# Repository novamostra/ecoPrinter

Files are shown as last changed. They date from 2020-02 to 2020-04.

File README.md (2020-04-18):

# ecoPrinter
ecoPrinter is an innovative device which can replace hard copies with **no interaction** file transferring, by implementing Android Beam and USB Printer Gadget functionality on a Raspberry PI Zero W.

Forget searching for Bluetooth devices or Wifi networks, enabling visibility, establishing a connection/pairing or setting up Wifi Direct, everything has become automated using (the unfortunately now deprecated) Android Beam. You just place your mobile device on the ecoPrinter while this is searching for a device (Red indication Light) and a few seconds later you can view the file on your mobile device as PDF. No matter if it is an image, document or a web-page, full backward compatibility is guaranteed because ecoPrinter appears as any other Printing device  on your computer.

The main idea for this device is to reduce the amount of paper we use and also help users organize and keep their receipts, invoices, documents with the minimum amount of effort.
<!--more-->
## How it works
1. The provider (owner of the device) connects the ecoPrinter and correlates the appropriate driver.
2. The provider of the ecoPrinter functionality simply selects the document to be printed and selects ecoPrinter as the preferable printer device.
3. The file is then send to the Raspberry Pi and is converted to PDF.
4. The WS2812B indicates to the user that it's time to place the mobile device to the ecoPrinter
5. With no other interaction the file is transferred to the mobile device as a PDF.

## Schematic
ecoPrinter schematic

## Configuration/Setup
1. Clone the repository
2. Set execute permission to setup.sh
```bash
sudo chmod +x setup.sh
```
3. Run as sudo
```bash
sudo ./setup.sh
```
4. On your Windows computer setup the appropriate printer driver running the following command:
```
printui /if /b "ecoPrinter" /f %windir%\inf\ntprint.inf /m "Microsoft PS Class Driver" /r "USB001"
```
5. Your ecoPrinter is Ready!

The complete step by step guide on how to create your own ecoPrinter is available on [instructables](https://www.instructables.com/id/EcoPrinter/).

## 3d files are also available at Thingverse
[Download from Thingverse](https://www.thingiverse.com/thing:4164764)

[Find out more](https://novamostra.com/2020/02/15/ecoprinter/)

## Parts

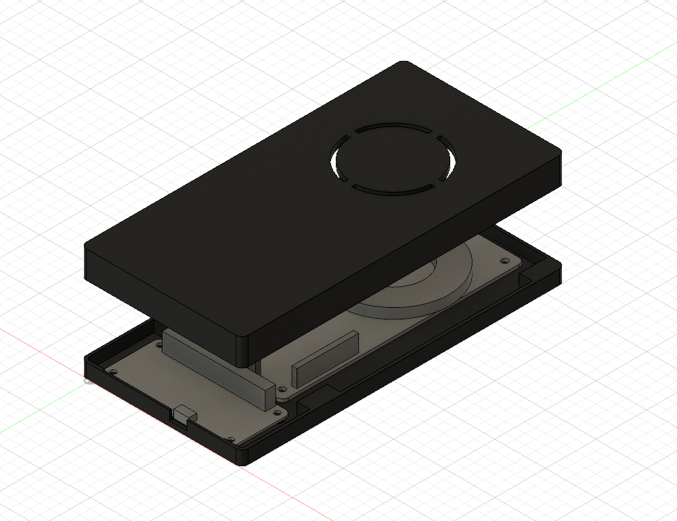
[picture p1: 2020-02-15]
enclosure/parts.png

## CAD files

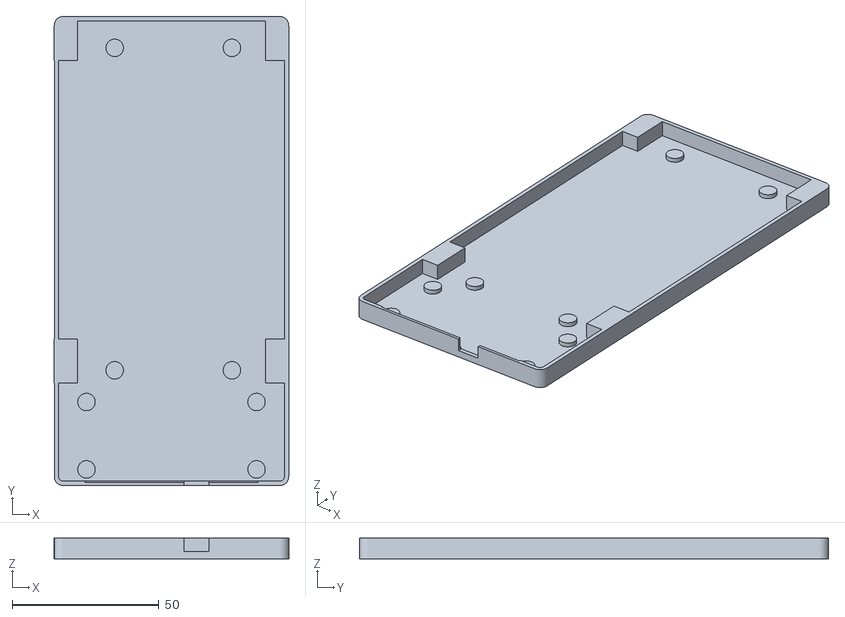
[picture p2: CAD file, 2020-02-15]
enclosure/ecoPrinterBottom.stl
80.0 x 160.0 x 7.00

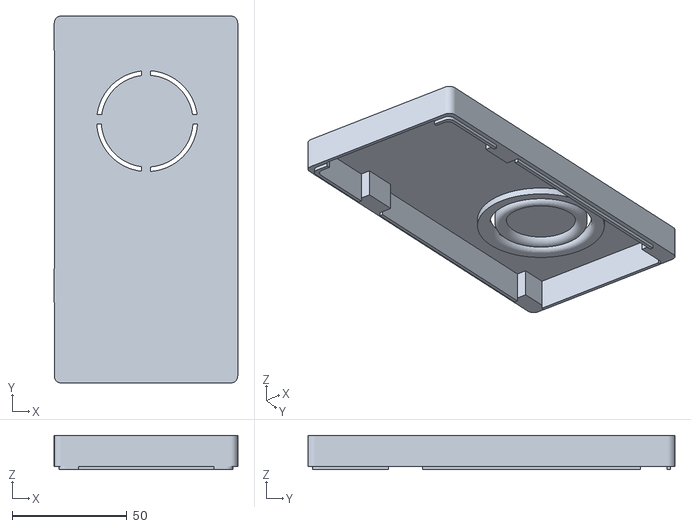
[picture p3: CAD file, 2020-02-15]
enclosure/ecoPrinterTop.stl
80.0 x 160.0 x 15.0

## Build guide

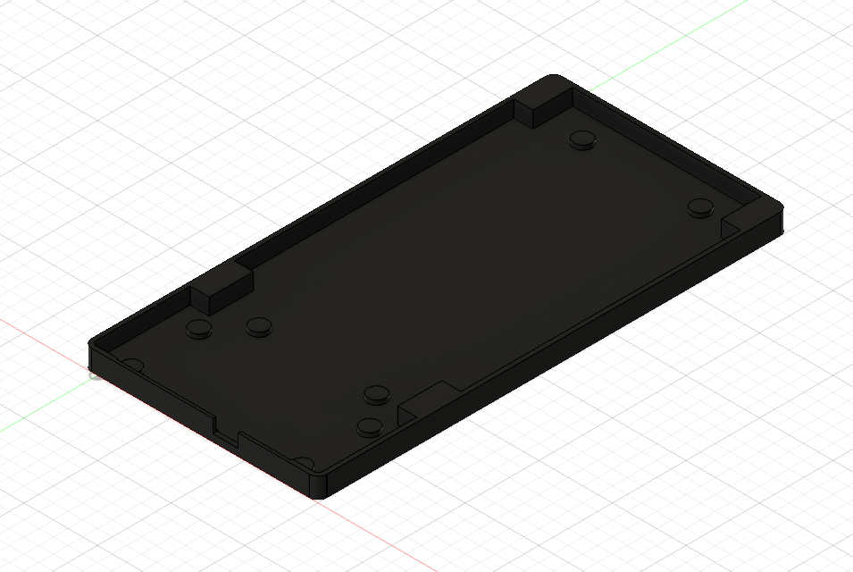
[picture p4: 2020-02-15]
enclosure/ecoPrinterBottom.png

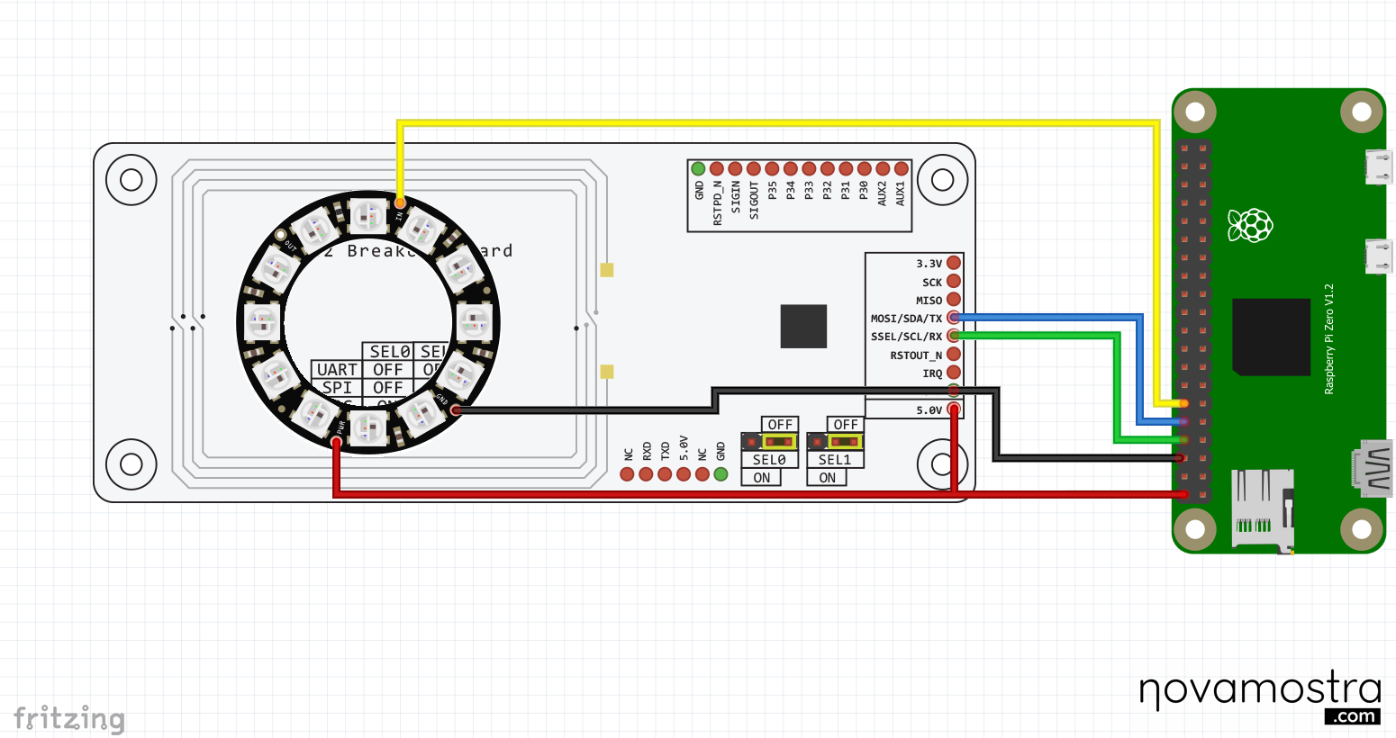
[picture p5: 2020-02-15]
schematic/ecoPrinterSchematic.png

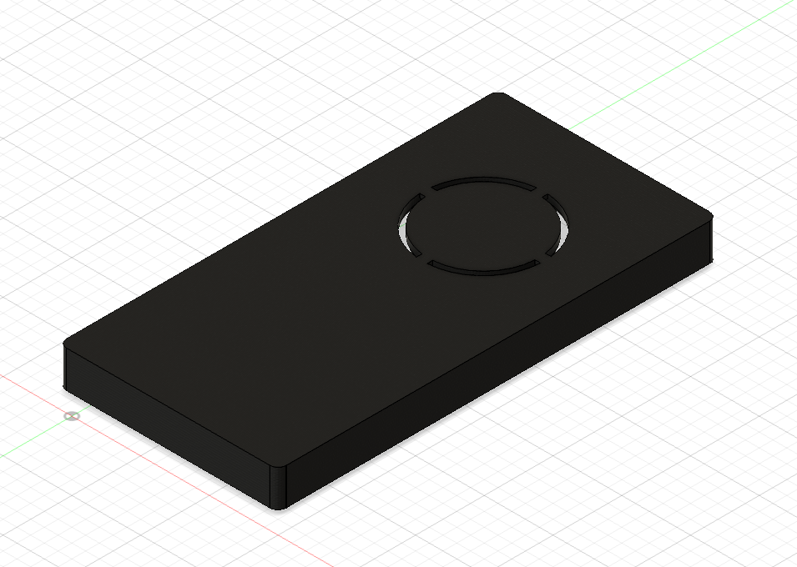
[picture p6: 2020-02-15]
enclosure/ecoPrinterTop.png

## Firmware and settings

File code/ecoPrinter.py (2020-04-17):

#!/usr/bin/env python
#ecoPrinter Printer Gadget handler
#author: novamostra.com
import os
import subprocess

import time
import logging

import board
from ledpanel import WS2812B


#init logger
logging.basicConfig(filename='log_printer',
                            filemode='w',
                            format='%(asctime)s,%(msecs)d %(name)s %(levelname)s %(message)s',
                            datefmt='%H:%M:%S',
                            level=logging.DEBUG)
log = logging.getLogger()

infile = os.open("/dev/g_printer0", os.O_RDONLY)

#check if prints directory exist or create it
if not os.path.isdir("prints"):
    os.mkdir("prints")

indicator = WS2812B(board.D18,12)
indicator.loop((0,0,200),0.02,3)
indicator.reset()

while True:
    charout = os.read(infile,512)
    if b"%!PS-Adobe-3.0" in charout:
        indicator.looping_ball((0,5,0),0.02)
        #maybe here I have to find the index in order to split the file?
        localtime = time.localtime()
        timeString = time.strftime("%Y%m%d%H%M%S",localtime)
        log.info("New file {0}".format(timeString))
        filename = "prints/" + timeString + ".ps"
        f = open(filename,"wb")
        f.write(charout)
    elif b"%%EOF" in charout:
        localtime = time.localtime()
        timeString = time.strftime("%Y%m%d%H%M%S",localtime)
        f.write(charout)
        f.close()
        os.system("ps2pdf " + filename + " " + filename + ".pdf")
        output_file = filename + ".pdf"
        localtime = time.localtime()
        timeString = time.strftime("%Y%m%d%H%M%S",localtime)
        indicator.stop()
        log.info("Conversion completed at {0}".format(timeString))
        output = subprocess.call(["python3", "beam.py",output_file])
    else:
        if not f.closed:
            f.write(charout)

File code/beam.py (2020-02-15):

#!/usr/bin/env python
#ecoPrinter Android NFC beam
#author: novamostra.com
import nfc
import ndef

import os
import sys
import threading
import subprocess

import logging

import configparser

# WS2812B requirements
import board
from ledpanel import WS2812B

# Init WS2812B led panel
indicator = WS2812B(board.D18,12)

# NFC Board serial port
NFC_DEVICE_PATH=""

# Raspberry PI's
LOCAL_BT_MAC=""
LOCAL_BT_NAME=""

#init logger
logging.basicConfig(filename='log',
                            filemode='w',
                            format='%(asctime)s,%(msecs)d %(name)s %(levelname)s %(message)s',
                            datefmt='%H:%M:%S',
                            level=logging.DEBUG)
log = logging.getLogger()


def init():
    #load device configuration
    load_config()
    
    #check if a file is supplied 
    log.debug(str(sys.argv[1]))
    if (len(sys.argv)==2):
        if (os.path.isfile(str(sys.argv[1]))):
            file = str(sys.argv[1])
            log.info("File {0} exists.".format(file))
            Beam().start(file)
        else:
            log.warning("File does not exist.")
    else:
        log.warning("Arguments mismatch.")

def load_config():
    global NFC_DEVICE_PATH, LOCAL_BT_NAME, LOCAL_BT_MAC
    config = configparser.ConfigParser()   
    configFilePath = r'ecoPrinter.conf'
    config.read(configFilePath)
    NFC_DEVICE_PATH = config['NFC_Device']['Path'].strip()
    LOCAL_BT_NAME = config['Bluetooth_Device']['Name'].strip()    
    LOCAL_BT_MAC = config['Bluetooth_Device']['Address'].strip()

    
def handover_connect(llc):
    client = nfc.handover.HandoverClient(llc)
    try:
        client.connect(recv_miu=128, recv_buf=2)
        log.info("connected to the remote handover server")
        return client
    except nfc.llcp.ConnectRefused:
        log.error("unable to connect to the handover server")

def handover_send(client, message, miu=128):
    if isinstance(message, (bytes, bytearray)):
        if not client.send_octets(message, miu):
            log.error("error sending handover request octets")
    else:
        if not client.send_records(message):
            log.error("error sending handover request records")

def handover_recv(client, timeout, raw=False):
    records = client.recv_records(timeout)

    if not records:
        log.error("no answer within {0} seconds".format(int(timeout)))

    if not records[0].type == "urn:nfc:wkt:Hs":
        log.error("unexpected message type '{0}'".format(records[0].type))

    return records

class Beam():
    def on_llcp_startup(self, llc):
        log.info("LLCP Startup")
        self.timer = threading.Timer(15.0, self.connection_timeout) 
        self.timer.start() 
        return llc

    def on_llcp_connect(self, llc):
        log.info("LLCP CONNECTED")
        self.timer.cancel()
        indicator.change_color((0,25,0))        
        threading.Thread(target=self.bluetooth_pair, args=(llc,)).start()
        llc.run()
        return False

    def terminate(self):
        indicator.stop()
        indicator.reset()        
        return self.status

    def start(self,file):
        indicator.looping_ball((20,0,0),0.02)
        self.status = False
        self.file=file
        self.init_connection()
        
    def connection_timeout(self):
        if(self.clf):
            self.clf.close()
        self.status=False
        self.terminate()

    def __init__(self):
        pass

    def bluetooth_pair(self, llc):
        client = handover_connect(llc)
        try:
            
            bt_record = ndef.BluetoothEasyPairingRecord(LOCAL_BT_MAC)
            bt_record.name = LOCAL_BT_NAME
            bt_record.device_name = LOCAL_BT_NAME
            bt_record.device_class = 0x10010C
            bt_record.add_service_class(0x1105)
            bt_record.add_service_class(0x1106)

            hr_record = ndef.HandoverRequestRecord("1.2", os.urandom(2))
            hr_record.add_alternative_carrier("active", bt_record.name)

            handover_send(client, [hr_record, bt_record])
            records = handover_recv(client, timeout=3.0)
            log.info("received {}".format(records[0].type))
            hs_record, bt_record = records

            if len(hs_record.alternative_carriers) != 1:
                log.warning("one selected carrier is expected")
            if bt_record.type != "application/vnd.bluetooth.ep.oob":
                log.warning("a Bluetooth carrier is expected")
            if bt_record.device_name == "":
                log.warning("empty local device name attribute")
            if bt_record.device_class is None:
                log.warning("there is no class of device attribute")
            if len(bt_record.service_class_list) == 0:
                log.warning("there are no service class UUIDs")
            if bt_record.simple_pairing_hash_256 is not None:
                log.warning("ssp hash not expected in just-works mode")
            if bt_record.simple_pairing_randomizer_256 is not None:
                log.warning("ssp rand not expected in just-works mode")

            if (not bt_record.device_address is None):
                indicator.change_color((0,0,25))
#                subprocess.call(["obexftp","-U","-b",str(bt_record.device_address.addr),"-B","12","-p",self.file])
                os.system("obexftp -U -b " + str(bt_record.device_address.addr) + " -B 12 -p " + self.file)
                self.status = True
        finally:
            self.terminate()            
            client.close()
            
    def init_connection(self):
        try:
            self.clf = nfc.ContactlessFrontend(NFC_DEVICE_PATH)
        except IOError as error:
            if error.errno == errno.ENODEV:
                log.info("no contactless reader found on " + path)
            elif error.errno == errno.EACCES:
                log.info("access denied for device with path " + path)
            elif error.errno == errno.EBUSY:
                log.info("the reader on " + path + " is busy")
            else:
                log.debug(repr(error) + "when trying " + path)

        llcp_options = {
            'on-startup': self.on_llcp_startup,
            'on-connect': self.on_llcp_connect,
            'role':       None,
            'brs':        2,
            'acm':        False,
            'rwt':        8,
            'miu':        2175,
            'lto':        500,
            'lsc':        3,
            'agf':        False,
            'sec':        False,
        }

        try:
            return self.clf.connect(llcp=llcp_options)
        finally:
            self.clf.close()

if __name__ == '__main__':
    init()
